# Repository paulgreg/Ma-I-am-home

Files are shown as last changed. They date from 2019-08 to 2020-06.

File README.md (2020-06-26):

# Ma, I’m home

That project is a connected button which, when pressed, send a SMS to people. It’s used by my son, to text me when he’s back from school.
You can [see it in action on youtube](https://www.youtube.com/watch?v=YSLezdGY_Ck).

## Instructions

### ESP8266 Connections

I’m using a ESP8266 ESP-12 with an adapter plate including resistors, not included in my schematic.

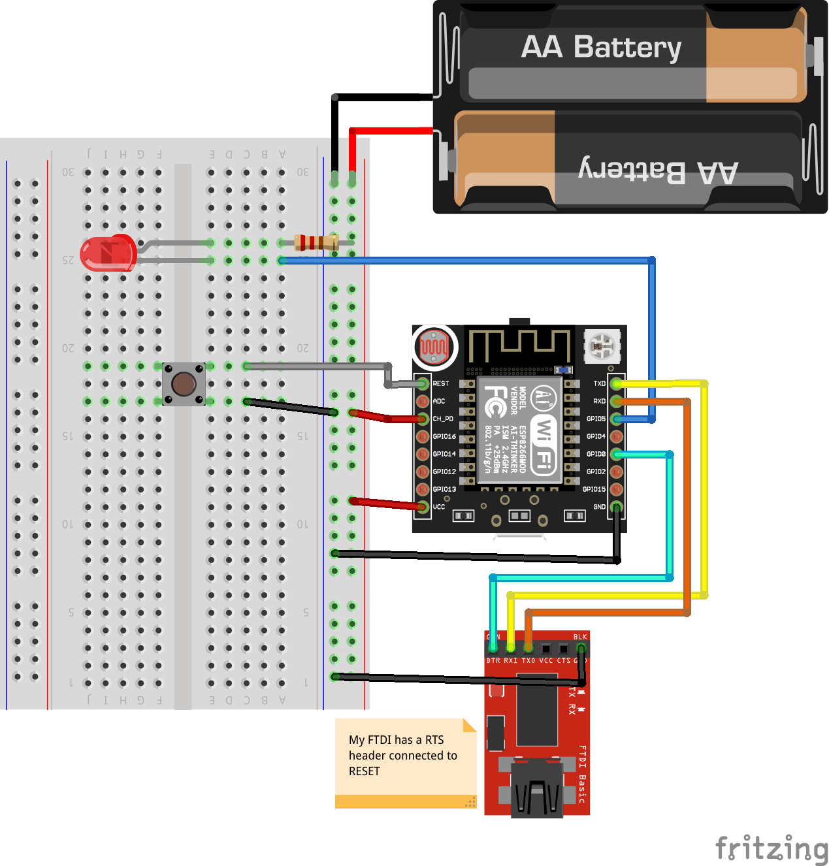
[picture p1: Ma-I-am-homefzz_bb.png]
connections


- VCC to 3.3
- Ground to ground
- CH_PD from ESP to VCC
- LED + connected to a 220 ohm resistor and to VCC
- LED - connected to GPIO5
- Button connected to ground and RESET on ESP
- RX from FTDI to TX on ESP
- TX from FTDI to RX on ESP
- DTR from FTDI to GPIO 0 on ESP
- RST from FTDI to RESET on ESP

## Software

copy `parameters.h.dist` to `parameters.h` and replace wifi SSID and password. You can use SMS free mobile API but it can only send SMS to your mobile phone, not any random number. You would have to change host and URL if you’re using another celullar provider.
Beware, you need to extract SHA1 TLS certificate finterprint and update it in order to make the TLS connection work.

In arduino IDE, set `Node MCU 1.0 (ESP-12E module)` before compiling.

## links

  * [ESP8266 official doc](https://github.com/espressif/esptool/wiki/ESP8266-Boot-Mode-Selection)
  * [A Beginner's Guide to the ESP8266](https://tttapa.github.io/ESP8266/Chap01%20-%20ESP8266.html)
  * [ESP8266 NodeMCU HTTPS Secured POST Request](https://circuits4you.com/2019/02/08/esp8266-nodemcu-https-secured-post-request/)
  * [ESP8266 Wi-Fi Button – DIY Amazon Dash Button Clone](https://randomnerdtutorials.com/esp8266-wi-fi-button-diy-amazon-dash-button-clone/)
  * [ESP8266 Pinout Reference](https://randomnerdtutorials.com/esp8266-pinout-reference-gpios/)
  * [Free Mobile SMS API](https://www.freenews.fr/freenews-edition-nationale-299/free-mobile-170/nouvelle-option-notifications-par-sms-chez-free-mobile-14817)

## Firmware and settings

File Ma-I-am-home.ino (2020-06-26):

#include <ESP8266WiFi.h>
#include <WiFiClientSecure.h>
#include "parameters.h"

// default LED on board is 2
// I’m using here GPIO 5 to connect a LED with a 220 ohm resistor
#define LED 5
#define BUTTON 13
#define WAIT 100
#define REQUEST_TIMEOUT 5000

#if VERIFY_CERTIFICATE
const char host_certificate_fingerprint[] PROGMEM = HOST_CERTIFICATE_FINGERPRINT
#endif

void setup() {
  // The button will trigger reset and so, boot the esp8266
  pinMode(LED, OUTPUT);
  pinMode(BUTTON, INPUT);
  Serial.begin(74880);
  while (!Serial);
  Serial.println("Connected button");
  blinkOnce();

  if (connectToWifi()) {
    for (int i = 0; i < URLS_SIZE; i++) {
      blinkOnce();
      get(HOST, URLS[i]);
      blinkOnce();
    }
    WiFi.mode(WIFI_OFF);
    longBlinkOnce();
  }

  Serial.println("Sleeping");
  ESP.deepSleep(0); // Sleeping until next time button is pressed, which will boot the microcontroller
}

void loop() {
  // sleeping at the end of setup so will never get here
}

boolean connectToWifi() {
  Serial.print("\nconnecting to ");
  Serial.println(WIFI_SSID);

  WiFi.forceSleepWake();
  WiFi.mode(WIFI_STA);
  WiFi.begin(WIFI_SSID, WIFI_PASSWORD);
  unsigned int retries = 100;
  while (WiFi.status() != WL_CONNECTED && (retries-- > 0)) {
    blinkOnce();
    Serial.print(".");
  }
  if (WiFi.status() != WL_CONNECTED) {
    Serial.println("\nWifi connection failed");
    return false;
  }
  Serial.println("");
  Serial.println("wifi connected");
  Serial.print("IP address: ");
  Serial.println(WiFi.localIP());
  Serial.println("");
  return true;
}

boolean get(const char* host, const char* url) {
  WiFiClientSecure client;
  boolean status = false;

  #if VERIFY_CERTIFICATE
  Serial.println("Checking certificate fingerprint");
  client.setFingerprint(host_certificate_fingerprint);
  #else
  Serial.println("Ignoring certificate fingerprint");
  client.setInsecure();
  #endif

  Serial.print(">  ");
  Serial.print(host);
  
  client.setTimeout(10000);

  unsigned int retries = 10;
  while(!client.connect(host, 443) && (retries-- > 0)) {
    blinkOnce();
    Serial.print(".");
  }

  if(!client.connect(host, 443)) {
    Serial.println("\nRequest failed");
    return false;
  }

  Serial.println(url);

  client.print(String("GET ") + url + " HTTP/1.1\r\n" +
               "Host: " + host + "\r\n" +
               "User-Agent: ESP8266\r\n" +
               "Connection: close\r\n\r\n");

  unsigned long timeout = millis();
  while (client.available() == 0) {
    delay(1);
    if (millis() - timeout > REQUEST_TIMEOUT) {
      Serial.println("client Timeout !");
      client.stop();
      return false;
    }
  }

  return client.connected();
}

void blinkOnce() {
  digitalWrite(LED, HIGH);
  delay(100);
  digitalWrite(LED, LOW);
  delay(100);
}

void longBlinkOnce() {
  for(int i = 0; i < 3; i++) {
    digitalWrite(LED, HIGH);
    delay(500);
    digitalWrite(LED, LOW);
    delay(500);
  }
}

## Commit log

2019-08-13 Add Fritzing schematics
    [Ma-I-am-homefzz.fzz]
2019-08-15 Stop trying to connect to wifi after some attempts...
    To not empty the battery !
    Also light code refactoring.
2019-09-17 Update limits...
    SMS wasn’t sent sometimes so try that
2020-06-26 Add the possibility to avoid fingerprint check...
    Beware, it may cause a leak of your id / password. Use it at your own
    risk
    [Ma-I-am-home.ino]
2020-06-26 Update sms-api.free-mobile.fr certificate fingerprint
2020-06-26 Update README.md about board to configure
